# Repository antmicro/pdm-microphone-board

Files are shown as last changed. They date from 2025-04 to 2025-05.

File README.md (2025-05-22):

# Microphone board

Copyright (c) 2024-2025 [Antmicro](https://www.antmicro.com)


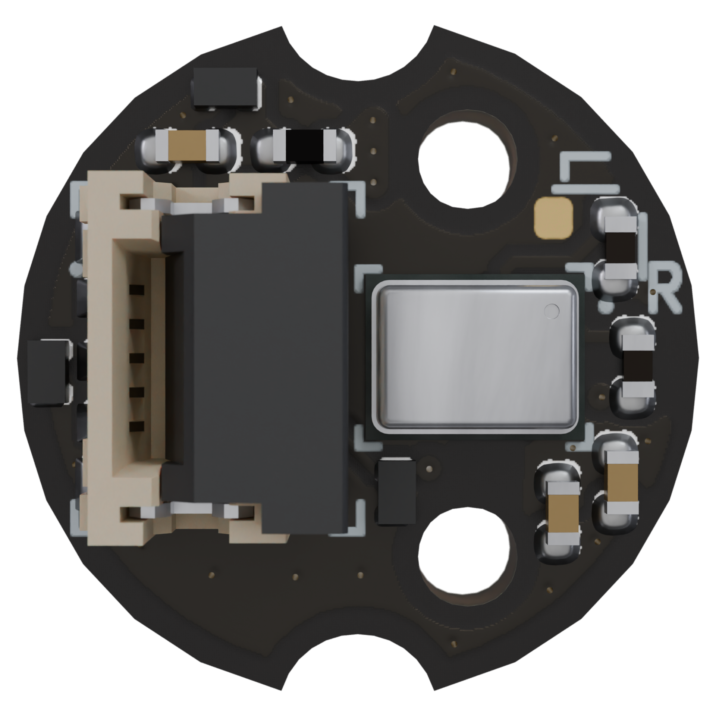
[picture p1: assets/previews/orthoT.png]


## Overview

This project contains open hardware design files for a microphone board with an SPH0644LM4H-1 PDM microphone.
The board break-routes PDM signals from the microphone to a zero insertion force connector.
Additionally, the board provides voltage filtering and ESD protection.

The design files were prepared in KiCad 8.x.

## Key features

* Knowles [SPH0644LM4H-1](https://www.mouser.com/datasheet/2/218/ph0644lm4h-1_revc-1518995.pdf)
* Zero insertion force connector for a 5 pin, 0.5 mm pitch FFC
* Selectable Left or Right channel audio transmitting
* Designed to fit an 11mm diameter opening
* Alignment cutouts for toolless mounting 

## Project structure

The main directory contains KiCad PCB project files, a LICENSE, and a README.
The remaining files are stored in the following directories:

* `doc` - contains schematics in PDF format
* `assets` - contains visual assets for showcasing this design on [Open Hardware Portal](https://openhardware.antmicro.com) and [System Designer](https://designer.antmicro.com)

## Licensing

This project is published under the [Apache-2.0](LICENSE) license.

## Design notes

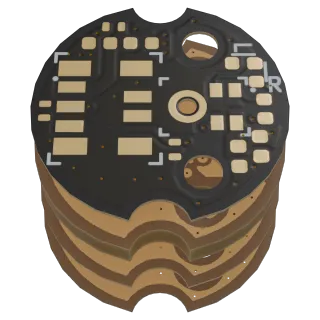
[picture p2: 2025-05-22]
assets/previews/layer1_thumbnail.webp

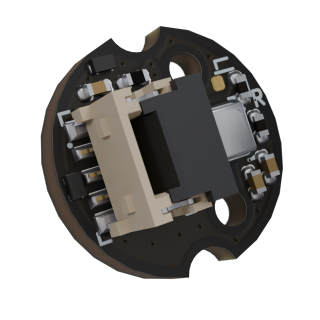
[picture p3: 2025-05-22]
assets/previews/leftT_thumbnail.png

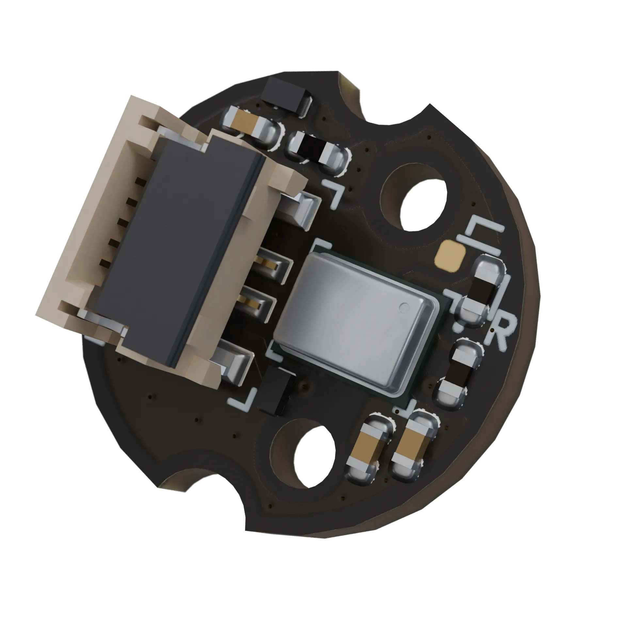
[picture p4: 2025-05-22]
assets/previews/rightT.webp

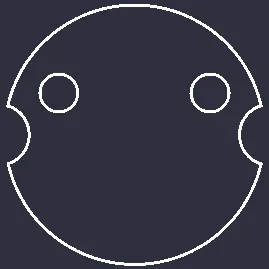
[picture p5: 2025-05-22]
assets/wireframe/wireframe_wireframe_descriptions_bottom.webp

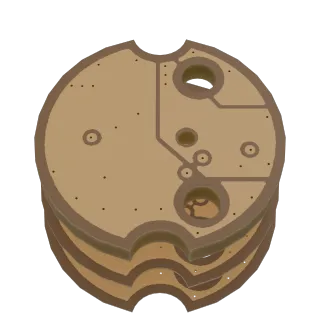
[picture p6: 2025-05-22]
assets/previews/layer3_thumbnail.webp

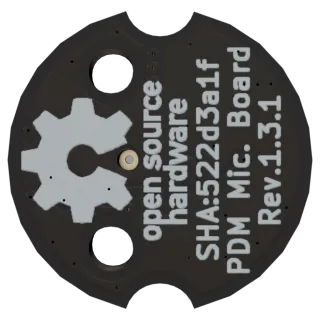
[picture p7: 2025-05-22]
assets/previews/orthoB_thumbnail.webp

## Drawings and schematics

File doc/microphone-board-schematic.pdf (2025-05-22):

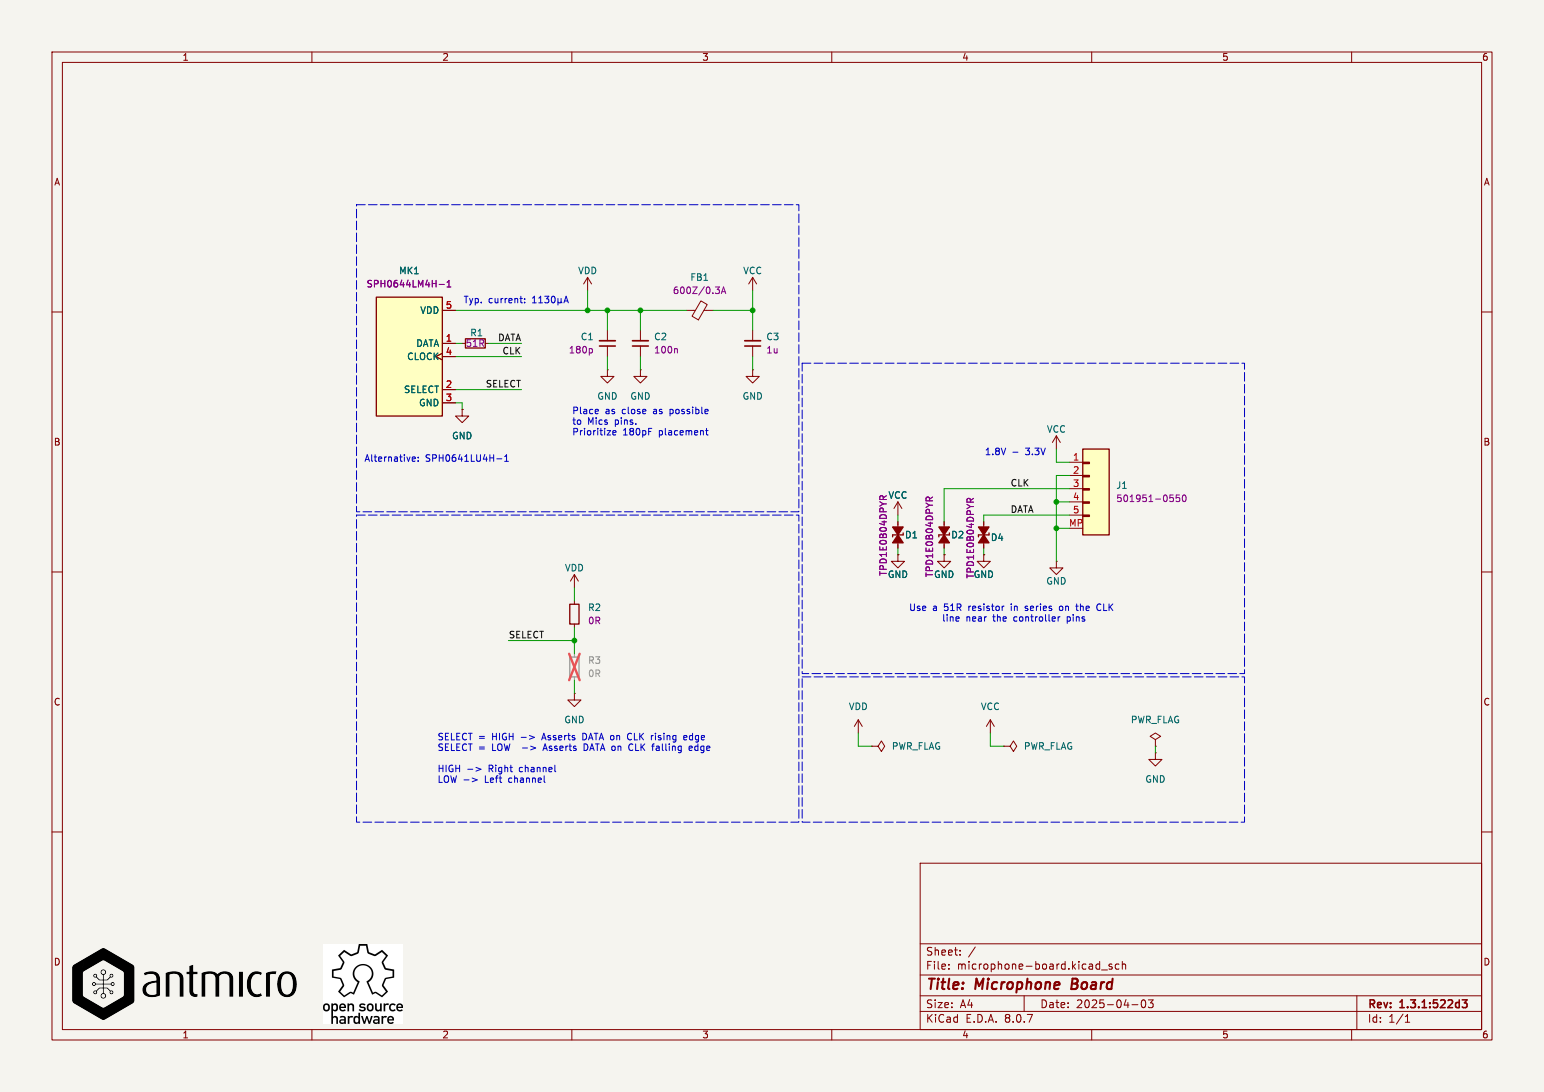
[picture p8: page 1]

File: microphone-board.kicad_sch Sheet: /
Id: 1/1 Title: Microphone Board

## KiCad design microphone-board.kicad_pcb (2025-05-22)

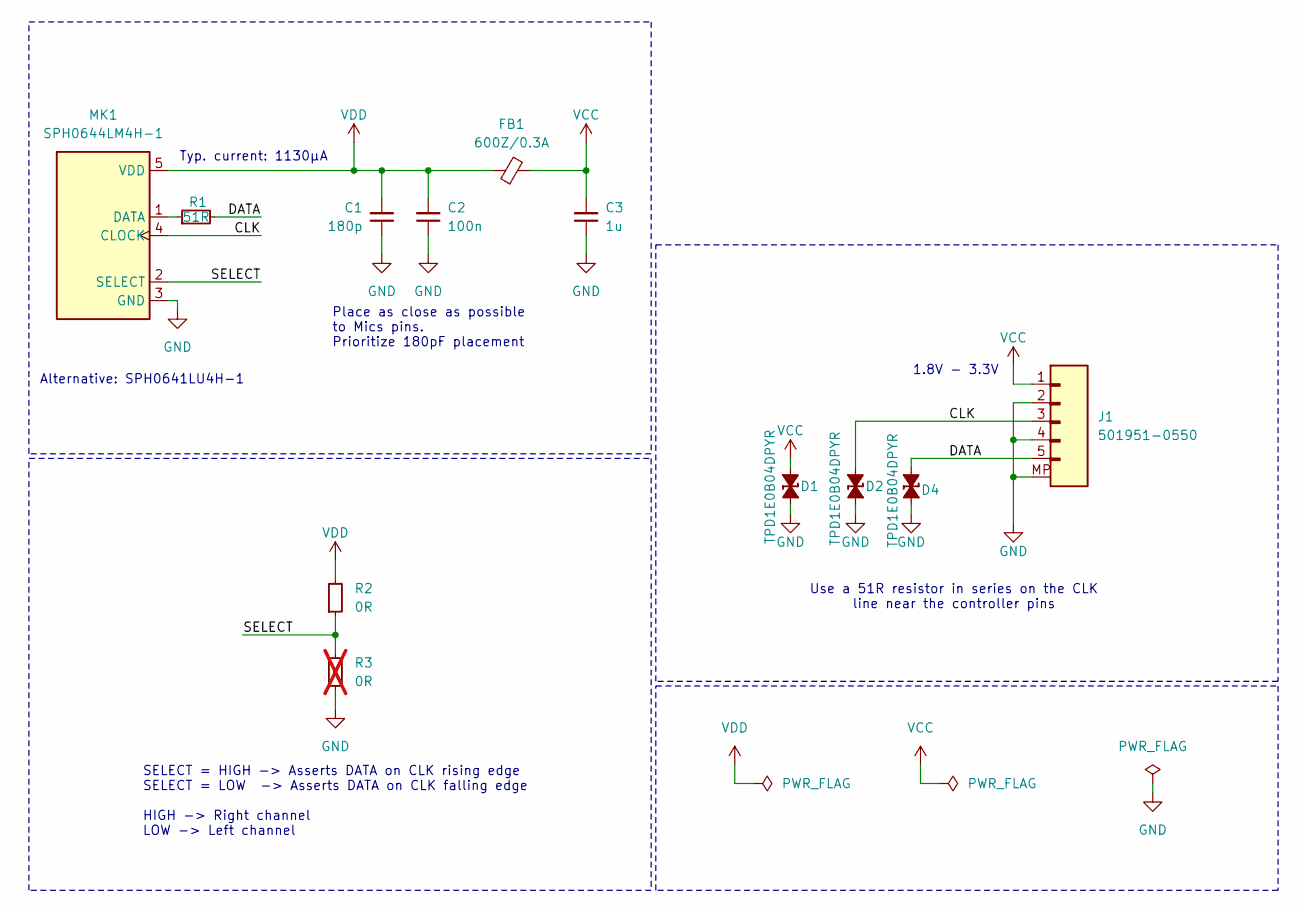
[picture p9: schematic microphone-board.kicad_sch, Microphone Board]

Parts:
C1: C_180p_0402; C_0402_1005Metric; MPN 04025A181JAT2A
C2: C_100n_50V_X8L_0402; C_0402_1005Metric; Voltage 50V; MPN GCM155L8EH104KE07D
C3: C_1u_0402; C_0402_1005Metric; MPN C1005X6S1A105K050BC
D1, D2, D4: TPD1E0B04_XDFN-2; XDFN-2_1x0.60mm; MPN TPD1E0B04DPYR
FB1: FB_600Z_0.3A_Murata-BLM15AG_0402; FB_0402_1005Metric; MPN BLM15AG601SN1D
J1: Conn_FFC_Molex_5019510550; MPN 501951-0550
MK1: MK_SPH0644LM4H-1; MPN SPH0644LM4H-1
R1: R_51R_0402; R_0402_1005Metric; Tolerance 1%; MPN CR0402-FX-51R0GLF
R2: R_0R_0402; R_0402_1005Metric; MPN ERJ2GE0R00X
R3: R_0R_0402; R_0402_1005Metric; MPN ERJ2GE0R00X; not fitted

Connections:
/CLK: D2.1 (C), J1.3, MK1.4 (CLOCK)
/DATA: D4.1 (C), J1.5, R1.2
/SELECT: MK1.2 (SELECT), R2.1, R3.2
GND: C1.1, C2.1, C3.1, D1.2 (A), D2.2 (A), D4.2 (A), J1.2, J1.4, J1.MP, MK1.3 (GND), R3.1
unnamed: MK1.1 (DATA), R1.1
VCC: C3.2, D1.1 (C), FB1.2, J1.1
VDD: C1.2, C2.2, FB1.1, MK1.5 (VDD), R2.2

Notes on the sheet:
1.8V - 3.3V
Use a 51R resistor in series on the CLK line near the controller pins
Place as close as possible to Mics pins. Prioritize 180pF placement
Alternative: SPH0641LU4H-1
Typ. current: 1130µA
SELECT = HIGH -> Asserts DATA on CLK rising edge SELECT = LOW -> Asserts DATA on CLK falling edge HIGH -> Right channel LOW -> Left channel

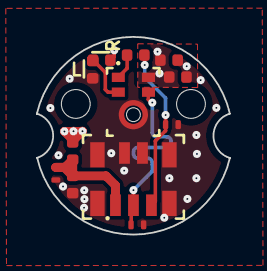
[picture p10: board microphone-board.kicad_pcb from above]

Board: 4 copper layers, 10.7 x 11.0 mm, 12 parts (0 on the bottom side), 7 nets.

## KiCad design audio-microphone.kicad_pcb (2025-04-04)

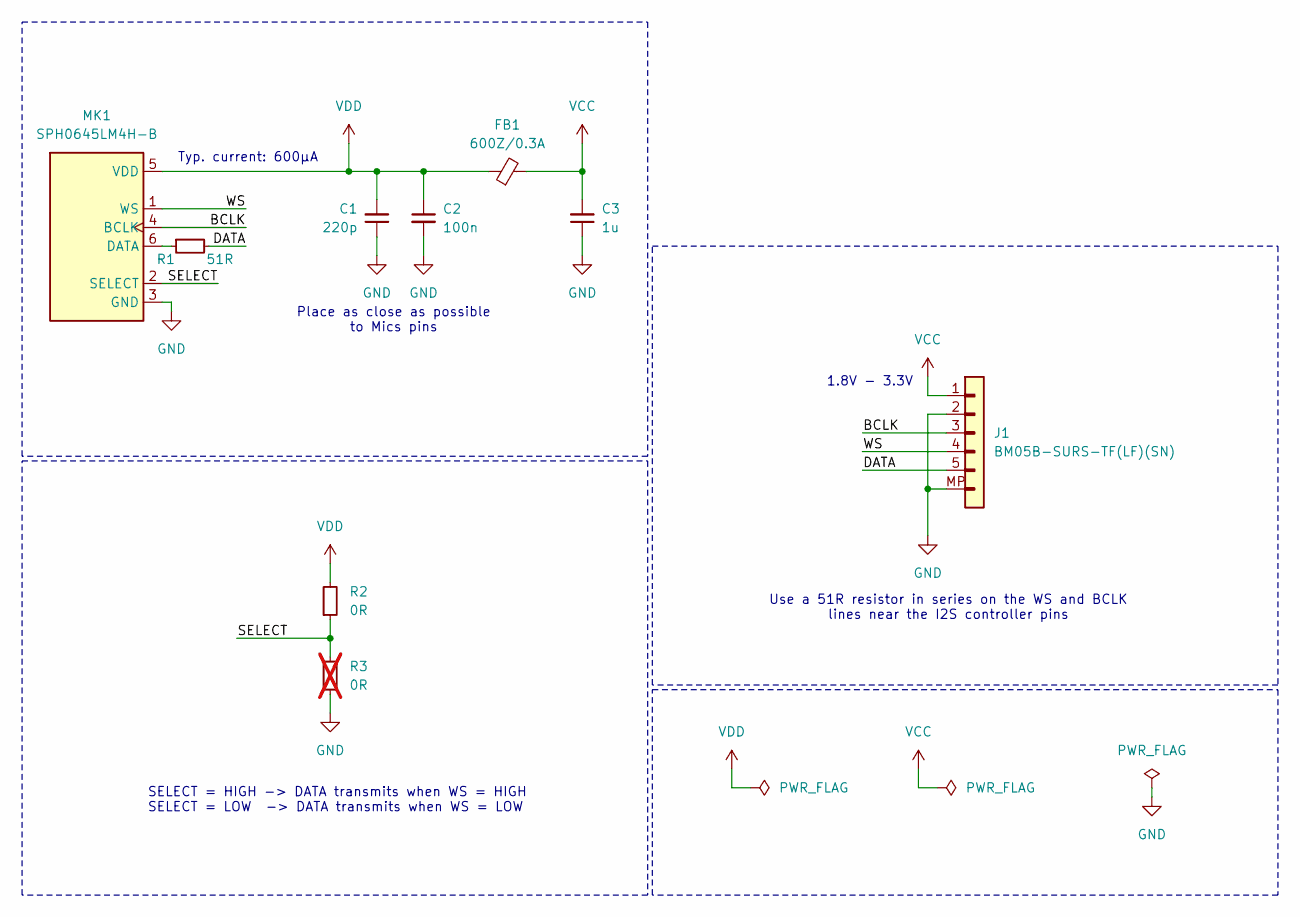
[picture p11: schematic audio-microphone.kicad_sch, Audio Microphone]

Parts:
C1: C_220p_0402; C_0402_1005Metric; MPN 04025C221JAT2A
C2: C_100n_0402; C_0402_1005Metric; Voltage 50V; MPN GRM155R61H104KE14D
C3: C_1u_0402; C_0402_1005Metric; MPN C1005X6S1A105K050BC
FB1: FB_600Z_0.3A_Murata-BLM15AG_0402; FB_0402_1005Metric; MPN BLM15AG601SN1D
J1: JST_SUR_1x5_BM05B-SURS-TB-LF-SN; Conn_JST_SUR_1x5_BM05B-SURS-TF-LF-SN; MPN BM05B-SURS-TF(LF)(SN)
MK1: MK_SPH0645LM4H-B; MPN SPH0645LM4H-B
R1: R_51R_0402; R_0402_1005Metric; Tolerance 1%; MPN CR0402-FX-51R0GLF
R2: R_0R_0402; R_0402_1005Metric; MPN ERJ2GE0R00X
R3: R_0R_0402; R_0402_1005Metric; MPN ERJ2GE0R00X; not fitted

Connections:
/BCLK: J1.3, MK1.4 (BCLK)
/DATA: J1.5, R1.2
/SELECT: MK1.2 (SELECT), R2.1, R3.2
/WS: J1.4, MK1.1 (WS)
GND: C1.1, C2.2, C3.1, J1.2, J1.MP, MK1.3 (GND), R3.1
unnamed: MK1.6 (DATA), R1.1
VCC: C3.2, FB1.2, J1.1
VDD: C1.2, C2.1, FB1.1, MK1.5 (VDD), R2.2

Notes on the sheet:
1.8V - 3.3V
Use a 51R resistor in series on the WS and BCLK lines near the I2S controller pins
Place as close as possible to Mics pins
Typ. current: 600µA
SELECT = HIGH -> DATA transmits when WS = HIGH SELECT = LOW -> DATA transmits when WS = LOW

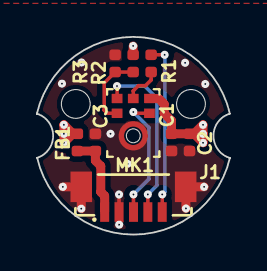
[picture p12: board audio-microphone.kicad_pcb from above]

Board: 4 copper layers, 10.7 x 11.0 mm, 9 parts (0 on the bottom side), 8 nets.

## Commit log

2025-04-04 [#71081] Design microphone board
    [audio-microphone.kicad_pcb, audio-microphone.kicad_sch]
2025-04-04 [#71550] Update sch with SPH0645LM4H-B mic
    [audio-microphone.kicad_sch]
2025-04-04 [#71550] Start placement
    [audio-microphone.kicad_pcb]
2025-04-04 [#71550] Route connections
    [audio-microphone.kicad_pcb, audio-microphone.kicad_sch]
2025-04-04 [#71550] Add new mounting system
    [audio-microphone.kicad_pcb]
2025-04-04 [#71550] Swap BCLK and WS, Fix outline
    [audio-microphone.kicad_pcb, audio-microphone.kicad_sch]
2025-04-04 [#71550] Update components
    [audio-microphone.kicad_pcb]
2025-04-04 [#71550] Update MK_SPH0645LM4H-B footprint
    [audio-microphone.kicad_pcb]
2025-04-04 [#71550] Correct board outline
    [audio-microphone.kicad_pcb]
2025-04-04 [#71550] Change PCB to 4 layers
    [audio-microphone.kicad_pcb]
2025-04-04 [#71550] Change FB1 to 0402 size one BLM15AG601SN1D
    [audio-microphone.kicad_pcb, audio-microphone.kicad_sch]
2025-04-04 [#71550] Re-arrange components, finish routing
    [audio-microphone.kicad_pcb]
2025-04-04 [#71550] Remove unnecessary vias
    [audio-microphone.kicad_pcb]
2025-04-04 [#71550] Limit board size to 11 mm in diameter, clear DRC
    [audio-microphone.kicad_pcb]
2025-04-04 [#71550] Remove dash from sch name
    [audio-microphone.kicad_sch]
2025-04-04 [#71550] Bump rev to 1.1.0
    [audio-microphone.kicad_pcb, audio-microphone.kicad_sch]
2025-04-04 [#71550] Rename and update assets
    [microphone-pcb.kicad_pcb, microphone-pcb.kicad_sch, microphone-pcb.step]
2025-04-04 [#71986] Update connector on sch
    [microphone-pcb.kicad_sch]
2025-04-04 [#71986] Continue placement
    [microphone-pcb.kicad_pcb]
2025-04-04 [#71986] Bump rev to 1.2.0, route connections
    [microphone-pcb.kicad_pcb, microphone-pcb.kicad_sch]
2025-04-04 [#71986] Adjust grid and aux origin
    [microphone-pcb.kicad_pcb]
2025-04-04 [#71986] Add tvs protection
    [microphone-pcb.kicad_sch]
2025-04-04 [#71986] Replace capacitors with C0G and X8L dielectrics types
    [microphone-pcb.kicad_sch]
2025-04-04 [#71986] Import Changes to the PCB, Place TVS
    [microphone-pcb.kicad_pcb]
2025-04-04 [#71986] Update date and align the name with the sch
    [microphone-pcb.kicad_pcb]
2025-04-04 [#71986] Fix R3 malformed DNP properties
    [microphone-pcb.kicad_pcb, microphone-pcb.kicad_sch]
2025-04-04 [#71986] Update zones clearance
    [microphone-pcb.kicad_pcb]
2025-04-04 [#71986] Update Silk L/R channels
    [microphone-pcb.kicad_pcb]
2025-04-04 [#71986] Update Rule for inner layers 0.4 mm clearance copper to edge
    [microphone-pcb.kicad_pcb]
2025-04-04 [#71249] Update name
    [microphone-board.kicad_pcb, microphone-board.kicad_sch, microphone-board.step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]
2025-04-04 [#71249] Update assets
    [microphone-board-HEAD-rev.1.2.0-54b7feff.step, microphone-board.step]
2025-04-04 [#72278] Bump rev to 1.3.0, Update project date
    [microphone-board.kicad_pcb, microphone-board.kicad_sch]
2025-04-04 [#72278] Replace the microphone with MK_SPH0644LM4H-1 (PDM)
    [microphone-board.kicad_sch]
2025-04-04 [#72278] Route connections
    [microphone-board.kicad_pcb]
2025-04-04 [#72278] Set TVS MPN to visible
    [microphone-board.kicad_pcb, microphone-board.kicad_sch]
2025-04-04 [#72278] Improve power planes
    [microphone-board.kicad_pcb]
2025-04-04 [#72278] Update components from library
    [microphone-board.kicad_pcb, microphone-board.kicad_sch]
2025-04-04 [#72278] Update assets
    [microphone-board-HEAD-rev.1.2.0-54b7feff.step]
2025-04-07 [#75547] Add license and logotype
    [microphone-board.kicad_pcb, microphone-board.kicad_sch]
2025-05-22 [#77860] Add stackup.csv
    [microphone-board.kicad_pcb, stackup.csv]

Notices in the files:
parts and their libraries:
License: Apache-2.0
